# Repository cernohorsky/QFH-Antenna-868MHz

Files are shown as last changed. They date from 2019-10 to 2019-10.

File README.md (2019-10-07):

# Quadrifilar Helix Antenna for 868 MHz
Quadrifilar Helix Antenna is omnidirectional circularly polarized antenna. It's ability to receive or transmit a tight beam of
circularly polarized radiation while minimizing unwanted radiation perfect fits especially for satellite communication. This 3D model helps to achieve correct shape of antenna segments which has crucial effect for correct circular polarization.

Antenna is made from 2 pcs of 0.8mm silver plated copper wire, with total length 357 mm and 339.4 mm. 
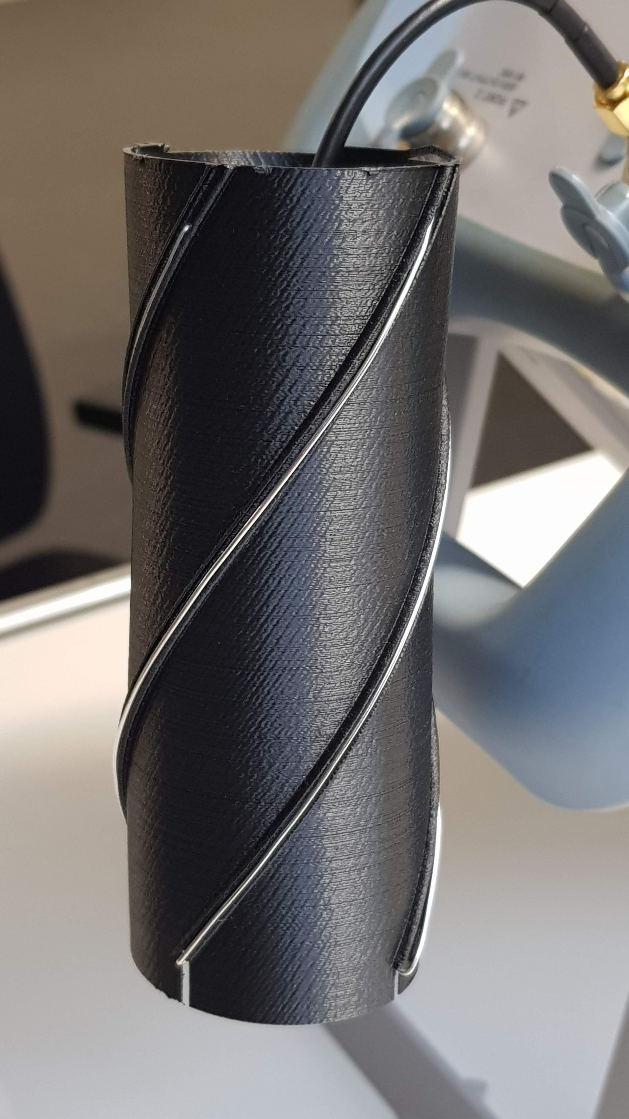
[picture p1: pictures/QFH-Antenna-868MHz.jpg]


Antenna feed

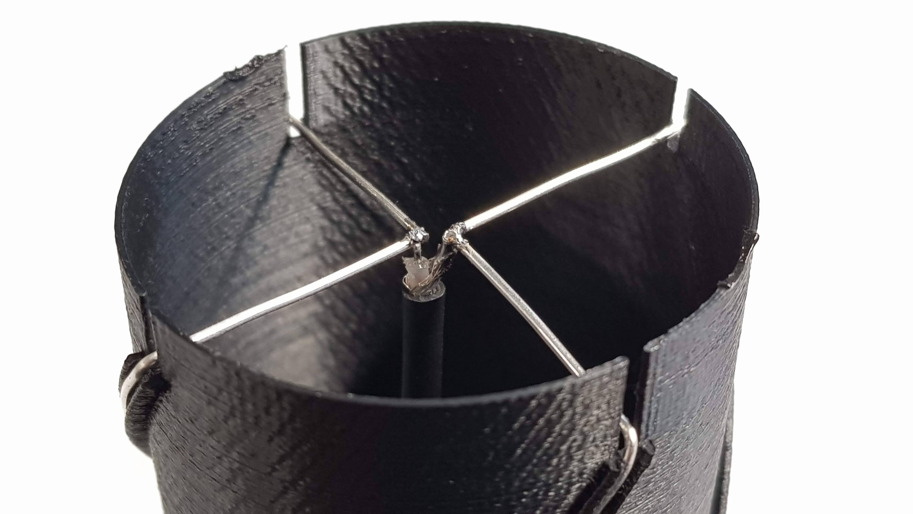
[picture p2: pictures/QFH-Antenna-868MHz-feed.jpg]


RG174 coaxial cable with SMA connector

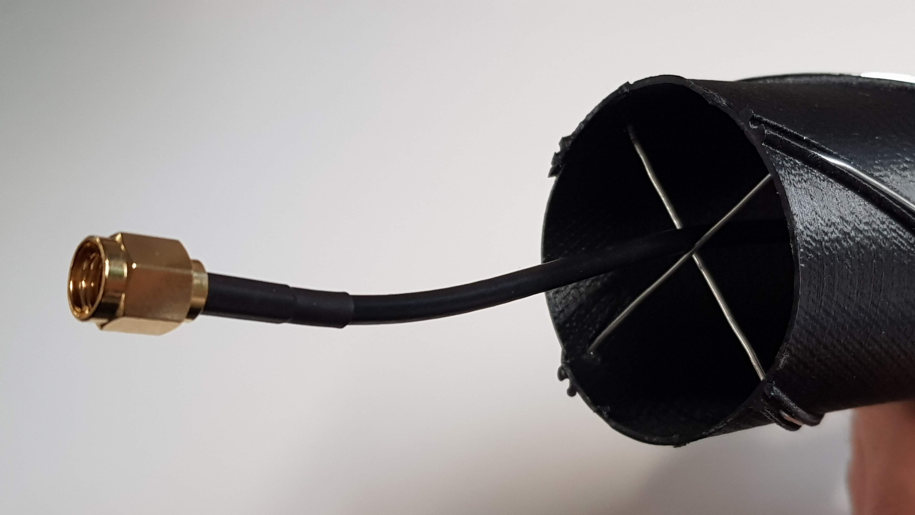
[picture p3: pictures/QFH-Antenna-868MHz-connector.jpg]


Antenna spectral characteristic

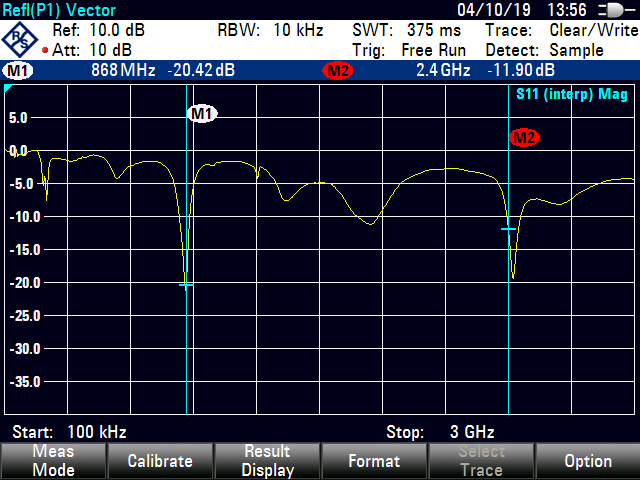
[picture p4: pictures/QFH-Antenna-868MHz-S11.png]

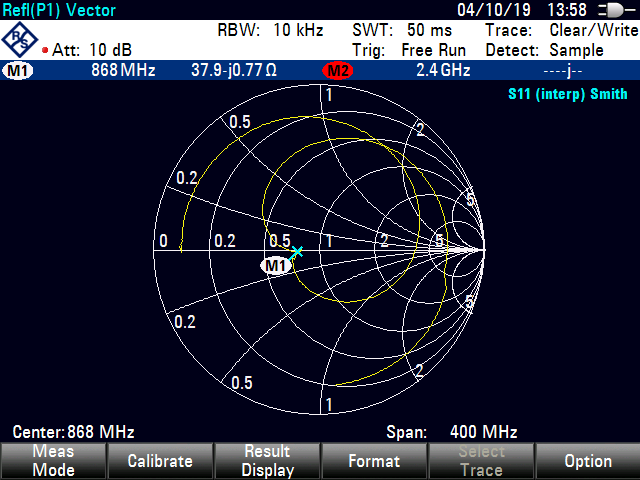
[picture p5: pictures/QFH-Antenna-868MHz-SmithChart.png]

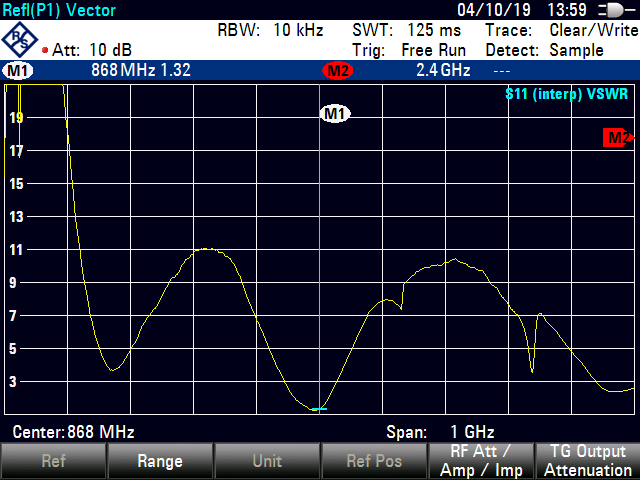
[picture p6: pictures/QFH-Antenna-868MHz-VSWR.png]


Calculated in:
http://jcoppens.com/ant/qfh/calc.en.php

<b>Warning. 3D model add parasitic capacity to antenna which moves resonant frequency. This was corrected by calculating antenna for higher frequeny (913 MHz). Changing any parameter must be verified by measurement.</b>
https://github.com/cernohorsky/QFH-Antenna-868MHz/blob/master/pictures/QFH-Antenna-868MHz-Param.jpg

Original 3D model:
http://www.thingiverse.com/thing:634205

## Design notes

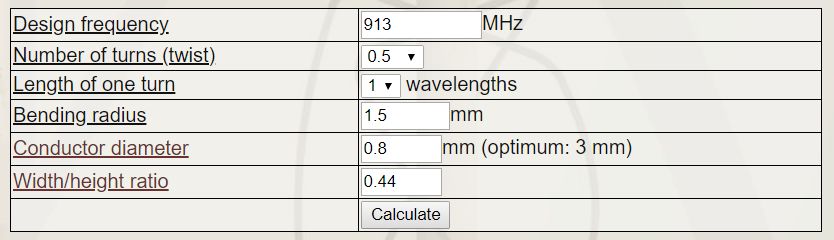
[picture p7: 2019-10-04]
pictures/QFH-Antenna-868MHz-Param.jpg

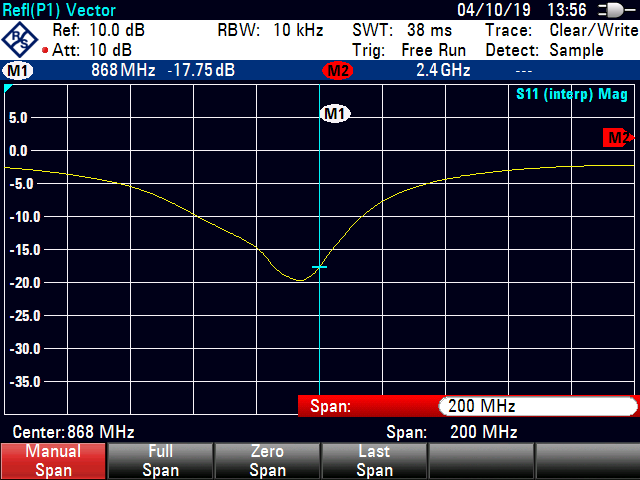
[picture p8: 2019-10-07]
pictures/QFH-Antenna-868MHz-S11-Zoom.png

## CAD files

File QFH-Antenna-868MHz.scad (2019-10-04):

// OpenSCAD script for a 868 MHz ISM band "quadrifilar helix antenna".
// The design originated in: http://www.thingiverse.com/thing:634205
// -------------------------------------------------------------
// Dimensions calculated with John Coppens webpage java script
// @ http://jcoppens.com/ant/qfh/calc.en.php
// Input params:
// Center frequency = 913 MHz
// Numbers of turns = 0.5
// Length of one turn = 1
// Bending radius = 1.5 mm
// Conductor diameter = 0.8 mm
// Width/height ratio = 0.44
// 
// -------------------------------------------------------------


$fn=80;

PI = 3.14159265358979;

D1 = 46.6; // mm large helix1 diameter.
D2 = 44.3; // mm small helix2 diameter.
HH1 = 107.8; // mm height of helix1.
HH2 = 102.5; // mm height of helix2.

WIRE = 1; // mm diameter.

CYLH = 120; // mm height of support cylinder.
CYLH2 = CYLH/2; // the half-height of the support cylinder.
SLICES = 60;

HWIRE11 = CYLH2-HH1/2; // place the four hole-pairs at these heights.
HWIRE12 = CYLH2-HH2/2;
HWIRE21 = CYLH2+HH1/2;
HWIRE22 = CYLH2+HH2/2;

EXTRUSION_WIDTH=0.6;

pedestal_height = 1;   // designed for use the MLAB standard 12mm screws.
mount_hole = 3.5;
clear = 0.175;

MLAB_grid_xoffset = 4.2;
MLAB_grid_yoffset = 4.2;
MLAB_grid = 10.16;


// some internal calculations. quite hairy math.
THETA1 = atan2(HH1,D1*PI); // Thetas are used for projecting the wirechannel cross-section onto the xy-plane.
THETA2 = atan2(HH2,D2*PI);
echo("theta1=",THETA1,"  -  theta2=",THETA2);

XSI1 = ((CYLH/HH1*180)-180); // extra rotation beyond the height of helix1. half above, half below.
XSI2 = ((CYLH/HH2*180)-180); // extra rotation beyond the height of helix2.
echo("xsi1=",XSI1," - xsi2=",XSI2);



//------------ Safety grid parameters---------------------------

nY = 5;
nX = 5;


meshX=100;
meshY=100;

// width of solid part of grid
meshSolid=1.2;

meshSpaceX = (meshX - meshSolid*nX)/nX;
meshSpaceY = (meshY - meshSolid*nY)/nY;




module base(){
    union()
    {
        for (i=[1:nX-1]) {
                 translate([i*(meshSolid+meshSpaceX) - meshSolid/2,0,0]) cube(size=[meshSolid, meshY, pedestal_height],center=false);
        }

        for (i=[1:nY-1]) {
                translate([0,i*(meshSolid+meshSpaceY) - meshSolid/2,0]) cube(size=[meshX, meshSolid, pedestal_height],center=false);

        }
    }
}


// test helix1.
module helix1(rot1=0)
{
	linear_extrude(height=50, twist=-XSI1-180, slices=SLICES) 
		rotate([0,0,rot1-XSI1/2]) translate([D1,0,0]) projection() scale([1,1/sin(THETA1),1]) wirechannel();
}

// test helix2.
module helix2(rot2=90)
{
	color("red") linear_extrude(height=50, twist=-XSI2-180, slices=SLICES) 
		rotate([0,0,rot2-XSI2/2]) translate([D2,0,0]) projection() scale([1,1/sin(THETA2),1]) wirechannel();
}



// definition of the wire channel by CSG. 
// used for projecting outline onto the xy-plane.
module wirechannel()
{
	difference()
	{
		cylinder(h=2, r=WIRE*0.8, center=true);

		translate([0,0,-0.1]) 
            cylinder(h=3, r=WIRE/2, center=true);

		translate([1.5*WIRE,0,0]) 
            cube([3*WIRE,WIRE,4], center=true);
	}
}

// definition of elliptic cylinder by CSG.
// used for projecting outline onto xy-plane.
module ellipse_base()
{
	scale([1,D2/D1,1]) 
        difference(){ 
            cylinder(h=1, r=(D1/2-WIRE/2), center = true); 
            cylinder(h=2, r=(D1/2 - WIRE/2 - EXTRUSION_WIDTH), center = true); 
        }
}

// just a elliptic torus.
// (penalty for using $fn quality.)
module torus(Rmajor=10, Rminor=1, h1=25)
{
	translate([0,0,h1]) scale([1,D2/D1,1]) rotate_extrude(convexity = 10) translate([Rmajor, 0, 0]) circle(r = Rminor); 
}

// the composite structure of support cylinder, wire channels, holes and cut-outs.
module composite()
{
	difference()
	{
		union()
		{
			// combine all elements in one extrude and twist.
			// helix1's.
			linear_extrude(height=HWIRE21, twist=-XSI1/2-180, slices=SLICES)
			{
				rotate([0,0,0-XSI1/2]) translate([D1/2,0,0]) projection() scale([1,1/sin(THETA1),1]) wirechannel();
				rotate([0,0,180-XSI1/2]) translate([D1/2,0,0]) projection() scale([1,1/sin(THETA1),1]) wirechannel();
			}
			// helix2's.
			linear_extrude(height=HWIRE22, twist=-XSI2/2-180, slices=SLICES)
			{
				rotate([0,0,90-XSI2/2]) translate([D2/2,0,0]) projection() scale([1,1/sin(THETA2),1]) wirechannel();
				rotate([0,0,270-XSI2/2]) translate([D2/2,0,0]) projection() scale([1,1/sin(THETA2),1]) wirechannel();
			}
			// elliptic support cylinder.
			linear_extrude(height=CYLH, twist=-XSI1/2-180, slices=SLICES)
			{
				rotate([0,0,0-XSI1/2]) projection(cut=true) ellipse_base();
			}

			// half-height marker on cylinder
			//rotate([0,0,90]) torus(Rmajor=(D1/2-WIRE/2), Rminor=0.2, h1=CYLH2);
		}
		union()
		{
			// lower hole pairs.
			translate([0,0,HWIRE11]) rotate([0,90,0]) cylinder(h=3*HH1, r=WIRE/2, center=true);
			translate([0,0,HWIRE12]) rotate([90,0,0]) cylinder(h=3*HH1, r=WIRE/2, center=true);

			// upper hole slots.
			translate([0,0,HWIRE21]) rotate([0,90,0]) cylinder(h=3*HH1, r=WIRE/2, center=true);
			translate([0,0,HWIRE22]) rotate([90,0,0]) cylinder(h=3*HH1, r=WIRE/2, center=true);

			translate([0,0,HWIRE21+CYLH2]) cube([CYLH,WIRE,CYLH], center=true);
			translate([0,0,HWIRE22+CYLH2]) cube([WIRE,CYLH,CYLH], center=true);
		}
	}
	translate([-50,-50,0])
		base();
}

module drillholes()
{
	// lower hole pairs.
	translate([0,0,HWIRE11]) rotate([0,90,0]) cylinder(h=3*HH1, r=WIRE/3, center=true);
	translate([0,0,HWIRE12]) rotate([90,0,0]) cylinder(h=3*HH1, r=WIRE/3, center=true);

	// upper hole pairs.
	translate([0,0,HWIRE21]) rotate([0,90,0]) cylinder(h=3*HH1, r=WIRE/3, center=true);
	translate([0,0,HWIRE22]) rotate([90,0,0]) cylinder(h=3*HH1, r=WIRE/3, center=true);
}

//wirechannel();
//helix1(rot1=0);
//helix1(rot1=180);
//helix2(rot2=90);
//helix2(rot2=270);
//drillholes();
//ellipse_base();
//base();

// MAIN()
composite();

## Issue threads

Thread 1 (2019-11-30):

Symetrizační člen pro napájení antény

kaklik, 2019-11-30:
Ukazuje se jako velmi nepraktické řešení dráty přiletovat na spodu, nebo vrchu antény k sobě společně s koaxiálním kabelem. Kromě toho, že je to časově náročné tak je to i velmi nespolehlivý spoj, který je nejčastější příčinou vzniku problémů s anténou.

Jako rozumné řešení mi přijde návrh malého tenkého plošného spoje (klidně čtvercového), na kterém bude symetrizační člen, např. [transformátor](https://www.minicircuits.com/pdfs/TC1-1-13MX+.pdf).

Na plošném spoji by bylo vhodné označit [obě možnosti zapojení](https://uuki.kapsi.fi/qha_simul.html).

Také by bylo dobré, kdyby plošný spoj obsahoval RF konektor pro přímé připojení koaxiálního kabelu a úplně se tak odstranila nutnost letování při montáži antény. Jako vhodný konektor mi přijde SMA do PCB.

PCB s konektorem a symetrizačním členem by mělo jít namontovat do horní i spodní části antény na dráty o průměru 0.5-2mm.
Velikost PCB je zřejmě omezena frekvenčním rozsahem použitého symetrizačního členu, protože by byla škoda, kdyby symetrizační člen byl na vyšší frekvenci, než nejmenší anténa, která na něj půjde namontovat.

kaklik, 2020-11-05:
Zřemě vyřešeno návrhem: https://github.com/ODZ-UJF-AV-CR/QFHBAL01

Closed 2020-11-05.

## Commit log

2019-10-04 Increased wirechannel constant for better printing
2019-10-07 Files rename
    [QFH-Antenna-868MHz.scad]
